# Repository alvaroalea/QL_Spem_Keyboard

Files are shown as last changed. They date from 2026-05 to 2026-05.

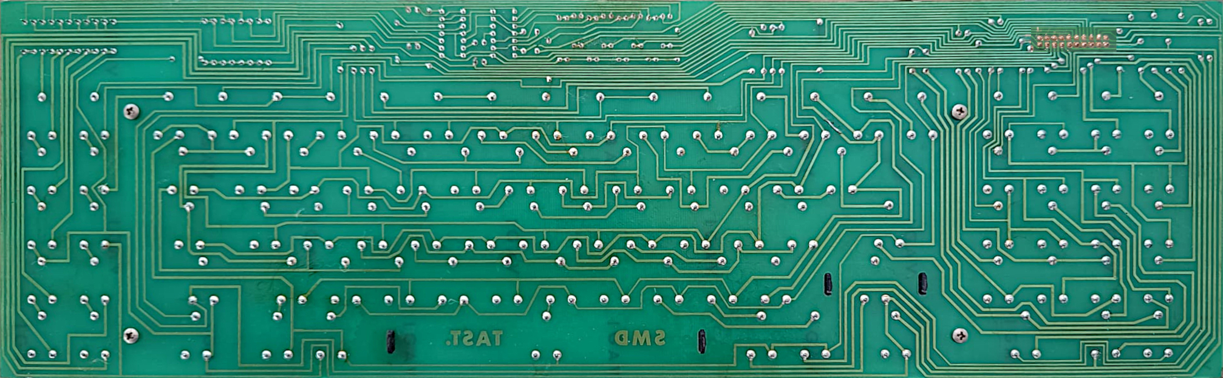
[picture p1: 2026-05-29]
Docs/PCB_solderside2.jpeg

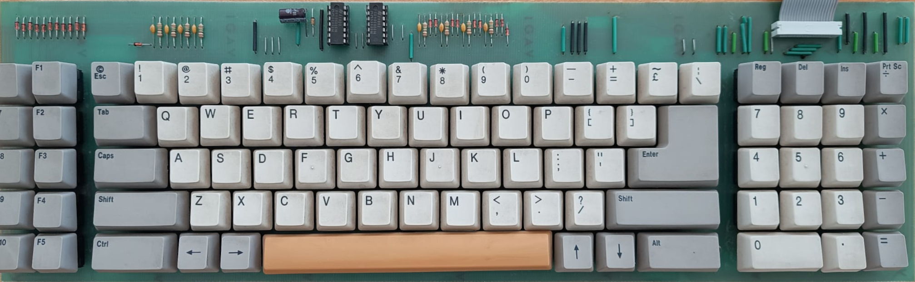
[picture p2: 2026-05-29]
Docs/PCB_compside2.jpeg

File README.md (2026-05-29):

# QL_Spem_Keyboard

Recreation of the mechanical keyboard for Sinclair QL computer by brand Spem

# WARNING: DO NOT USE THIS PROJECT IS NOT TESTED AND MISSING THINGS

Spem SRL, a italian company manufacture in 1986 a conversion kit for the Sinclair QL, named "System 2",
This include a aluminium desktop case with space for up to two 3 1/2" drives, the QL original Power supply and a Sinclair QL main board, to create a complete moderm desktop computer.

The case also incorporate a backplane where you can install a memory expansion and a disk interface.

The System 2 come with a full mechanical Keyboard, including numeric keys and 10 function keys, Spem use a unique aproach, and instead to provida a normal PC keyboard with a DIN-5 conector, design a specific one that connect directly to the keyboard conectors of the original Sinclair QL, and provide the aditional keys.

This is easy identificable because of the 20 cores ribbon cable the go from the keyboard to the case.

This project try to recreate this keyboard as identical as possible.
 
# Technical Details

The keyboard use keyswitch from Japanesse brand Futaba, referene MA-41 "Tombstone" because the top of the key is similar a tomb stone, with a cross emboss in the middle, while today's tipical keyswitchs the cross raise over the key.

This keyswitch has 3 legs, 2 of they are probably internally conected, to facilitate the develop of matrix keyboards using only 1 side of the PCB.

The combinations of keys need for some keys, like the F-5 F-10 that are really F1 to F5 at same time that shift keys, are from a pair of IC of type 4066, that are integrated analog swites, to power this 2 ic a small circuit drain the power from the keyboards lines itself.

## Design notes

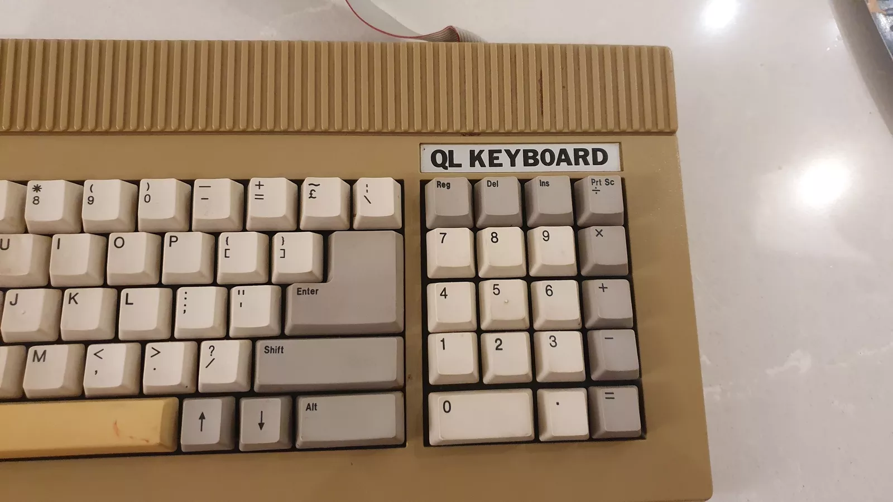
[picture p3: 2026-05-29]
Docs/s-l1601.webp

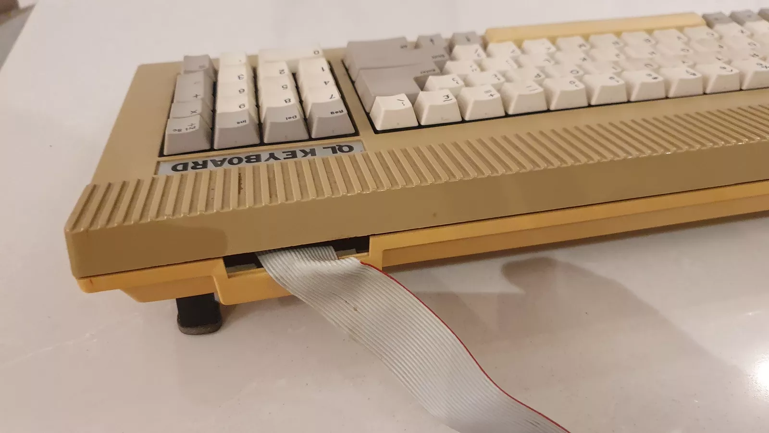
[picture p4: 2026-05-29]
Docs/s-l1611.webp

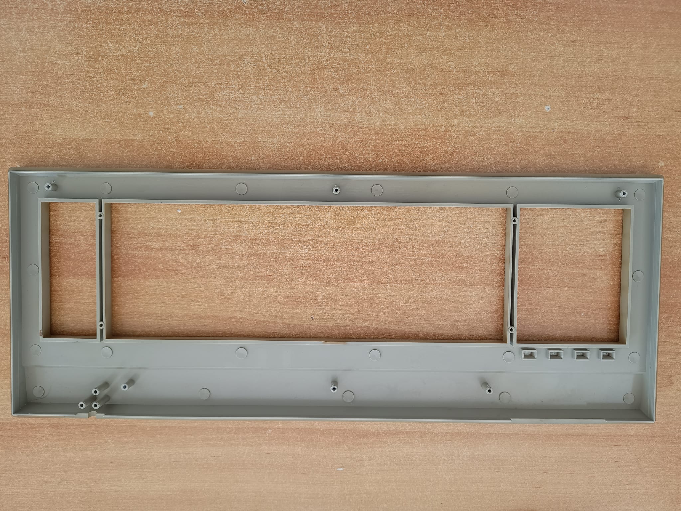
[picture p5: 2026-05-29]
Docs/Sin título4.jpeg

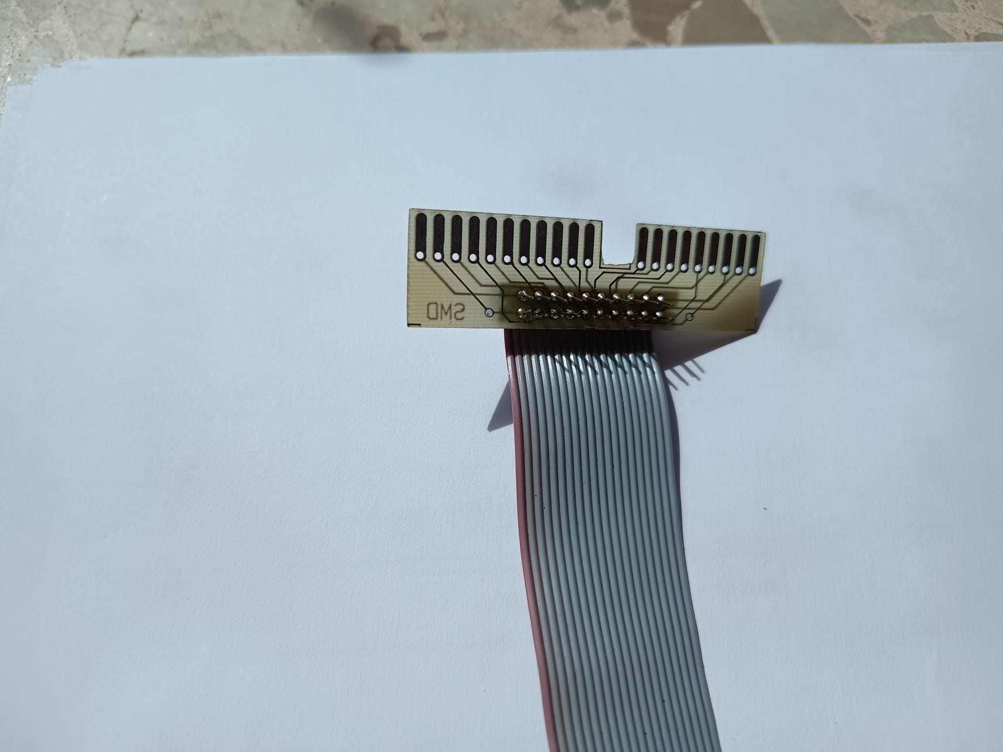
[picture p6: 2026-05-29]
Docs/Sin título9.jpeg

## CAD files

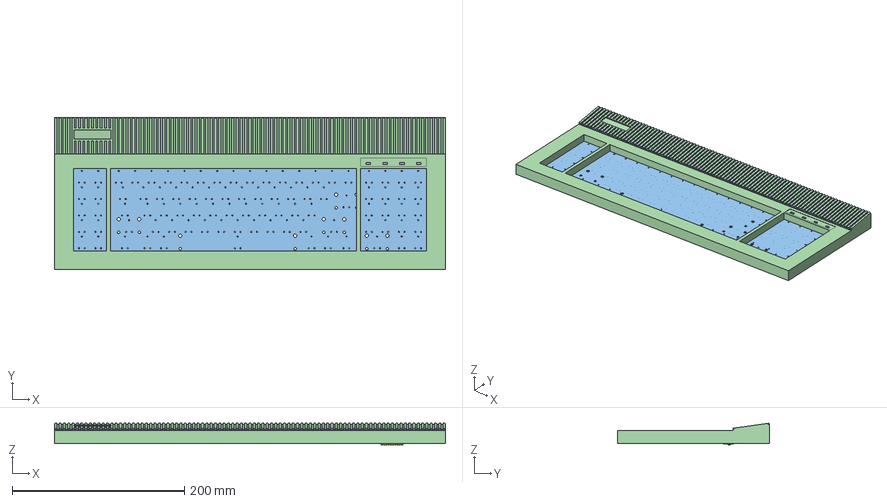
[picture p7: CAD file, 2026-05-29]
3D/SPEM_Case.FCStd
454.0 x 176.0 x 25.1 mm
D_DO-35_SOD27_P10.16mm_Horizontal
R_Axial_DIN0207_L6.3mm_D2.5mm_P10.16mm_Horizontal
R_Axial_DIN0207_L6.3mm_D2.5mm_P10.16mm_Horizontal001
R_Axial_DIN0207_L6.3mm_D2.5mm_P10.16mm_Horizontal002
R_Axial_DIN0207_L6.3mm_D2.5mm_P10.16mm_Horizontal003
R_Axial_DIN0207_L6.3mm_D2.5mm_P10.16mm_Horizontal004
D_DO-35_SOD27_P12.70mm_Horizontal
D_DO-35_SOD27_P10.16mm_Horizontal001
DIP-14_W7.62mm
D_DO-35_SOD27_P10.16mm_Horizontal002
R_Axial_DIN0207_L6.3mm_D2.5mm_P10.16mm_Horizontal005
D_DO-35_SOD27_P10.16mm_Horizontal003
D_DO-35_SOD27_P10.16mm_Horizontal004
D_DO-35_SOD27_P10.16mm_Horizontal005
D_DO-35_SOD27_P10.16mm_Horizontal006
C_Axial_L3.8mm_D2.6mm_P12.50mm_Horizontal
D_DO-35_SOD27_P10.16mm_Horizontal007
D_DO-35_SOD27_P7.62mm_Horizontal
D_DO-35_SOD27_P10.16mm_Horizontal008
D_DO-35_SOD27_P10.16mm_Horizontal009
D_DO-35_SOD27_P10.16mm_Horizontal010
D_DO-35_SOD27_P10.16mm_Horizontal011
R_Axial_DIN0207_L6.3mm_D2.5mm_P10.16mm_Horizontal006
D_DO-35_SOD27_P10.16mm_Horizontal012
R_Axial_DIN0207_L6.3mm_D2.5mm_P10.16mm_Horizontal007
R_Axial_DIN0207_L6.3mm_D2.5mm_P10.16mm_Horizontal008
R_Axial_DIN0207_L6.3mm_D2.5mm_P10.16mm_Horizontal009
R_Axial_DIN0207_L6.3mm_D2.5mm_P10.16mm_Horizontal010
R_Axial_DIN0207_L6.3mm_D2.5mm_P10.16mm_Horizontal011
D_DO-35_SOD27_P10.16mm_Horizontal013
D_DO-35_SOD27_P10.16mm_Horizontal014
DIP-14_W7.62mm001
R_Axial_DIN0207_L6.3mm_D2.5mm_P10.16mm_Horizontal012
R_Axial_DIN0207_L6.3mm_D2.5mm_P10.16mm_Horizontal013
D_DO-35_SOD27_P10.16mm_Horizontal015
D_DO-35_SOD27_P10.16mm_Horizontal016
R_Axial_DIN0207_L6.3mm_D2.5mm_P10.16mm_Horizontal014
D_DO-35_SOD27_P10.16mm_Horizontal017
D_DO-35_SOD27_P10.16mm_Horizontal018
D_DO-35_SOD27_P10.16mm_Horizontal019
R_Axial_DIN0207_L6.3mm_D2.5mm_P10.16mm_Horizontal015
PinHeader_2x10_P2.54mm_Horizontal
SPEN SINCLAIR QL_PCB
Cuerpo

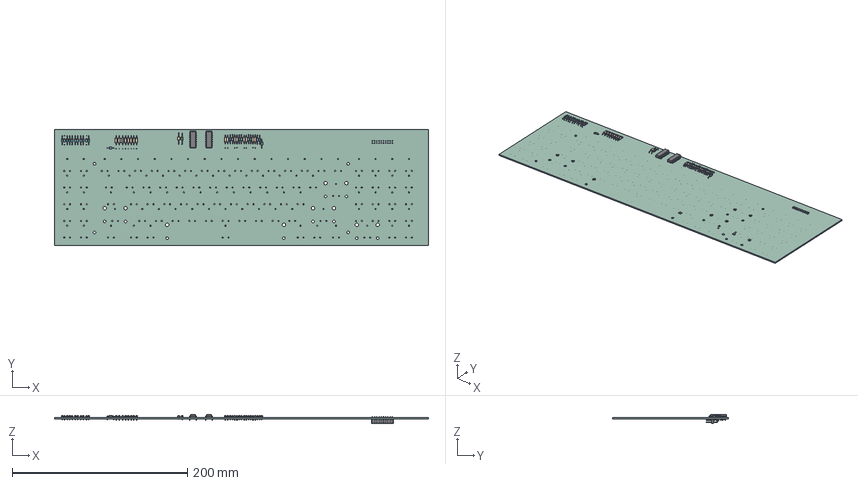
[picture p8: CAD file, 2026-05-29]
SPEN SINCLAIR QL/SPEN SINCLAIR QL.step
427.4 x 132.2 x 10.4 mm
D_DO-35_SOD27_P10.16mm_Horizontal x 20
R_Axial_DIN0207_L6.3mm_D2.5mm_P10.16mm_Horizontal x 16
D_DO-35_SOD27_P12.70mm_Horizontal
DIP-14_W7.62mm x 2
C_Axial_L3.8mm_D2.6mm_P12.50mm_Horizontal
D_DO-35_SOD27_P7.62mm_Horizontal
PinHeader_2x10_P2.54mm_Horizontal
SPEN SINCLAIR QL_PCB

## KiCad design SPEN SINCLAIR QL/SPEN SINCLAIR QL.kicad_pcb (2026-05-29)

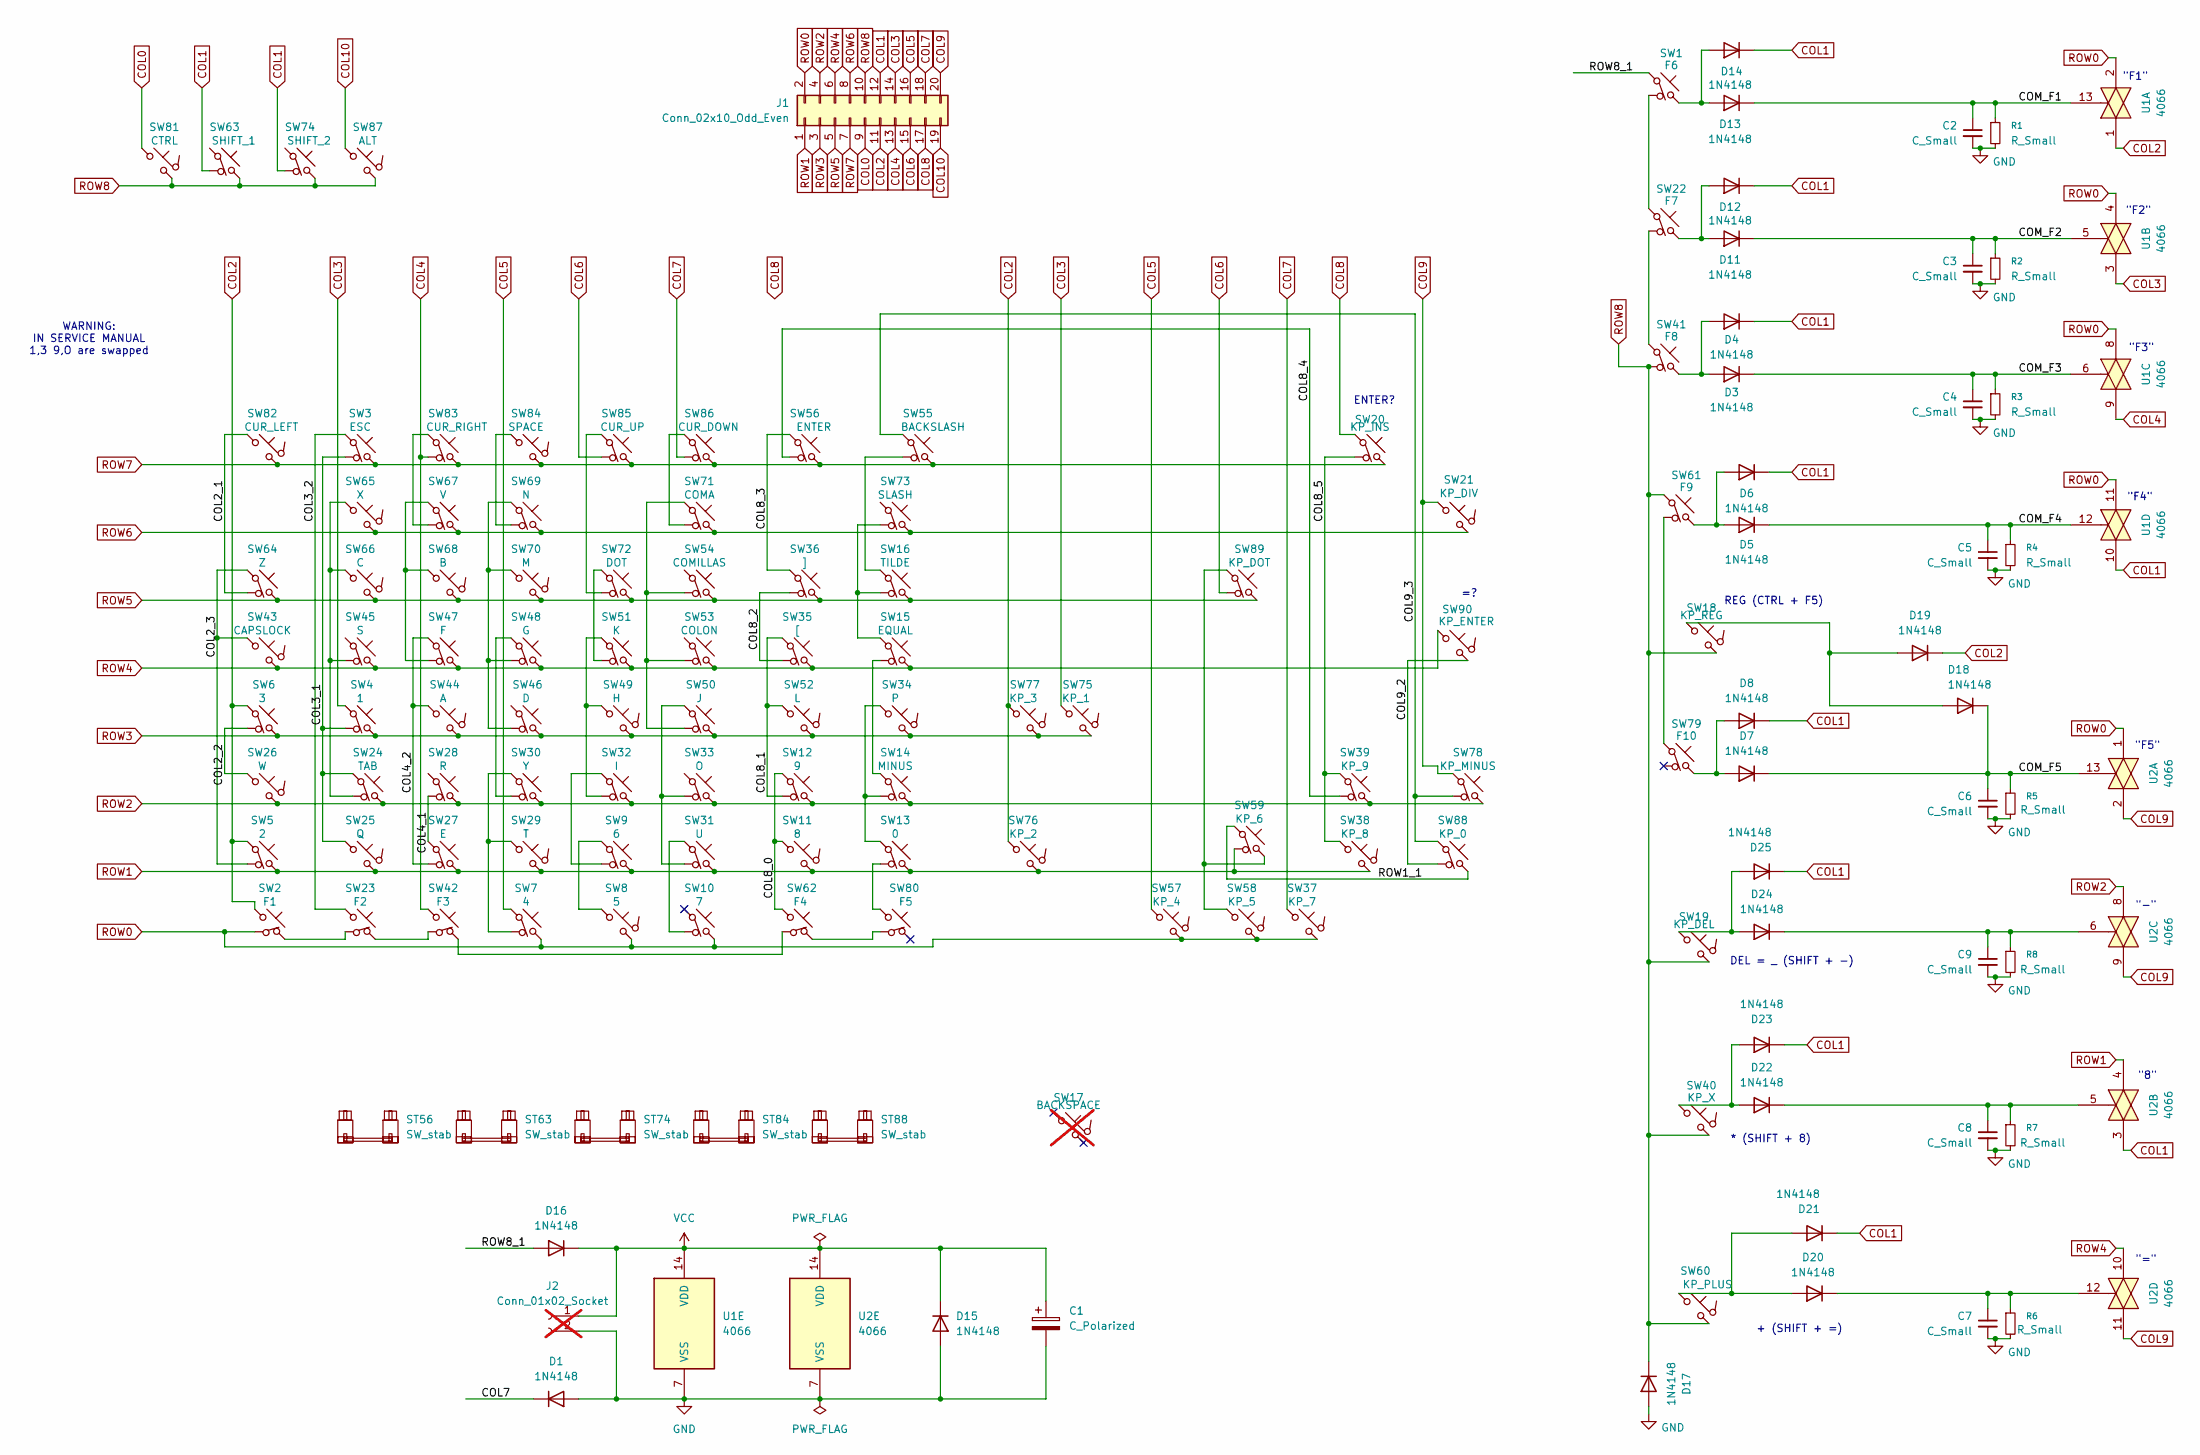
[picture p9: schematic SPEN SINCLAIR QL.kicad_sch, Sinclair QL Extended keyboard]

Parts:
C1: C_Polarized; C_Axial_L3.8mm_D2.6mm_P12.50mm_Horizontal
C2, C3, C4, C5, C6, C7, C8, C9: C_Small; C_Axial_DIN0207_L6.3mm_D2.5mm_P14.73mm_Horizontal
D1, D3, D4, D5, D6, D7, D8, D11, D12, D13, D14, D16, D18, D19, D20, D21, D22, D23, D24, D25: 1N4148; D_DO-35_SOD27_P10.16mm_Horizontal
D15: 1N4148; D_DO-35_SOD27_P12.70mm_Horizontal
D17: 1N4148; D_DO-35_SOD27_P7.62mm_Horizontal
J1: Conn_02x10_Odd_Even; PinHeader_2x10_P2.54mm_Horizontal
J2: Conn_01x02_Socket; PinHeader_1x02_P2.54mm_Horizontal; not fitted
R1, R2, R3, R4, R5, R6, R7, R8: R_Small; R_Axial_DIN0207_L6.3mm_D2.5mm_P14.73mm_Horizontal
ST56, ST63, ST74, ST88: SW_stab; Stabilizer_Cherry_MX_2.00u
ST84: SW_stab; Stabilizer_Cherry_MX_8.00u
SW1: F6; SW_Futaba_MA_PCB_1.00u
SW2: F1; SW_Futaba_MA_PCB_1.00u
SW3: ESC; SW_Futaba_MA_PCB_1.00u
SW4: 1; SW_Futaba_MA_PCB_1.00u
SW5: 2; SW_Futaba_MA_PCB_1.00u
SW6: 3; SW_Futaba_MA_PCB_1.00u
SW7: 4; SW_Futaba_MA_PCB_1.00u
SW8: 5; SW_Futaba_MA_PCB_1.00u
SW9: 6; SW_Futaba_MA_PCB_1.00u
SW10: 7; SW_Futaba_MA_PCB_1.00u
SW11: 8; SW_Futaba_MA_PCB_1.00u
SW12: 9; SW_Futaba_MA_PCB_1.00u
SW13: 0; SW_Futaba_MA_PCB_1.00u
SW14: MINUS; SW_Futaba_MA_PCB_1.00u
SW15: EQUAL; SW_Futaba_MA_PCB_1.00u
SW16: TILDE; SW_Futaba_MA_PCB_1.00u
SW17: BACKSPACE; SW_Futaba_MA_PCB_1.00u; not fitted
SW18: KP_REG; SW_Futaba_MA_PCB_1.00u
SW19: KP_DEL; SW_Futaba_MA_PCB_1.00u
SW20: KP_INS; SW_Futaba_MA_PCB_1.00u
SW21: KP_DIV; SW_Futaba_MA_PCB_1.00u
SW22: F7; SW_Futaba_MA_PCB_1.00u
SW23: F2; SW_Futaba_MA_PCB_1.00u
SW24: TAB; SW_Futaba_MA_PCB_1.00u
SW25: Q; SW_Futaba_MA_PCB_1.00u
SW26: W; SW_Futaba_MA_PCB_1.00u
SW27: E; SW_Futaba_MA_PCB_1.00u
SW28: R; SW_Futaba_MA_PCB_1.00u
SW29: T; SW_Futaba_MA_PCB_1.00u
SW30: Y; SW_Futaba_MA_PCB_1.00u
SW31: U; SW_Futaba_MA_PCB_1.00u
SW32: I; SW_Futaba_MA_PCB_1.00u
SW33: O; SW_Futaba_MA_PCB_1.00u
SW34: P; SW_Futaba_MA_PCB_1.00u
SW35: [; SW_Futaba_MA_PCB_1.00u
SW36: ]; SW_Futaba_MA_PCB_1.00u
SW37: KP_7; SW_Futaba_MA_PCB_1.00u
SW38: KP_8; SW_Futaba_MA_PCB_1.00u
SW39: KP_9; SW_Futaba_MA_PCB_1.00u
SW40: KP_X; SW_Futaba_MA_PCB_1.00u
SW41: F8; SW_Futaba_MA_PCB_1.00u
SW42: F3; SW_Futaba_MA_PCB_1.00u
SW43: CAPSLOCK; SW_Futaba_MA_PCB_1.00u
SW44: A; SW_Futaba_MA_PCB_1.00u
SW45: S; SW_Futaba_MA_PCB_1.00u
SW46: D; SW_Futaba_MA_PCB_1.00u
SW47: F; SW_Futaba_MA_PCB_1.00u
SW48: G; SW_Futaba_MA_PCB_1.00u
SW49: H; SW_Futaba_MA_PCB_1.00u
SW50: J; SW_Futaba_MA_PCB_1.00u
SW51: K; SW_Futaba_MA_PCB_1.00u
SW52: L; SW_Futaba_MA_PCB_1.00u
SW53: COLON; SW_Futaba_MA_PCB_1.00u
SW54: COMILLAS; SW_Futaba_MA_PCB_1.00u
SW55: BACKSLASH; SW_Futaba_MA_PCB_1.00u
SW56: ENTER; SW_Futaba_MA_PCB_1.00u
SW57: KP_4; SW_Futaba_MA_PCB_1.00u
SW58: KP_5; SW_Futaba_MA_PCB_1.00u
SW59: KP_6; SW_Futaba_MA_PCB_1.00u
SW60: KP_PLUS; SW_Futaba_MA_PCB_1.00u
SW61: F9; SW_Futaba_MA_PCB_1.00u
SW62: F4; SW_Futaba_MA_PCB_1.00u
SW63: SHIFT_1; SW_Futaba_MA_PCB_1.00u
SW64: Z; SW_Futaba_MA_PCB_1.00u
SW65: X; SW_Futaba_MA_PCB_1.00u
SW66: C; SW_Futaba_MA_PCB_1.00u
SW67: V; SW_Futaba_MA_PCB_1.00u
SW68: B; SW_Futaba_MA_PCB_1.00u
SW69: N; SW_Futaba_MA_PCB_1.00u
SW70: M; SW_Futaba_MA_PCB_1.00u
SW71: COMA; SW_Futaba_MA_PCB_1.00u
SW72: DOT; SW_Futaba_MA_PCB_1.00u
SW73: SLASH; SW_Futaba_MA_PCB_1.00u
SW74: SHIFT_2; SW_Futaba_MA_PCB_1.00u
SW75: KP_1; SW_Futaba_MA_PCB_1.00u
SW76: KP_2; SW_Futaba_MA_PCB_1.00u
SW77: KP_3; SW_Futaba_MA_PCB_1.00u
SW78: KP_MINUS; SW_Futaba_MA_PCB_1.00u
SW79: F10; SW_Futaba_MA_PCB_1.00u
SW80: F5; SW_Futaba_MA_PCB_1.00u
SW81: CTRL; SW_Futaba_MA_PCB_1.00u
SW82: CUR_LEFT; SW_Futaba_MA_PCB_1.00u
SW83: CUR_RIGHT; SW_Futaba_MA_PCB_1.00u
SW84: SPACE; SW_Futaba_MA_PCB_1.00u
SW85: CUR_UP; SW_Futaba_MA_PCB_1.00u
SW86: CUR_DOWN; SW_Futaba_MA_PCB_1.00u
SW87: ALT; SW_Futaba_MA_PCB_1.00u
SW88: KP_0; SW_Futaba_MA_PCB_1.00u
SW89: KP_DOT; SW_Futaba_MA_PCB_1.00u
SW90: KP_ENTER; SW_Futaba_MA_PCB_1.00u
U1, U2: 4066; DIP-14_W7.62mm_LongPads

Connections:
/COL2_1: SW64.3, SW82.1
/COL2_2: SW6.3, SW26.1
/COL2_3: SW5.3, SW43.1, SW64.1
/COL3_1: SW3.3, SW4.3, SW24.1, SW25.1
/COL3_2: SW3.1, SW23.2
/COL4_1: SW27.1, SW28.3
/COL4_2: SW27.3, SW44.1, SW47.1
/COL8_0: SW11.1, SW12.1, SW62.2
/COL8_1: SW12.3, SW35.1, SW52.1
/COL8_2: SW35.3, SW36.3
/COL8_3: SW36.1, SW56.1
/COL8_4: SW39.3, SW56.3
/COL8_5: SW20.3, SW38.1, SW39.1
/COL9_2: SW88.3, SW90.2
/COL9_3: SW55.1, SW78.3, SW88.1
/COM_F1: C2.1, D13.1 (K), R1.1, U1.13
/COM_F2: C3.1, D11.1 (K), R2.1, U1.5
/COM_F3: C4.1, D3.1 (K), R3.1, U1.6
/COM_F4: C5.1, D5.1 (K), R4.1, U1.12
/COM_F5: C6.1, D7.1 (K), D18.1 (K), R5.1, U2.13
/ROW1_1: SW59.1, SW88.2
/ROW8_1: D16.2 (A), SW1.1
COL0: J1.9, SW81.1
COL1: D4.1 (K), D6.1 (K), D8.1 (K), D12.1 (K), D14.1 (K), D21.1 (K), D23.1 (K), D25.1 (K), J1.12, SW63.3, SW74.3, U1.10, U2.3
COL2: D19.1 (K), J1.11, SW2.2, SW5.1, SW6.1, SW76.1, SW77.1, U1.1
COL3: J1.14, SW4.1, SW75.1, U1.3
COL4: J1.13, SW42.2, SW83.3, U1.9
COL5: J1.16, SW7.1, SW57.1
COL6: J1.15, SW85.3, SW89.3
COL7: D1.1 (K), J1.18, SW37.1, SW86.3
COL8: J1.17, SW20.1
COL9: J1.20, SW21.1, SW78.1, U2.2, U2.9, U2.11
COL10: J1.19, SW87.1
COM_8: C8.1, D22.1 (K), R7.1, U2.5
COM_MINUS: C9.1, D24.1 (K), R8.1, U2.6
COM_PLUS: C7.1, D20.1 (K), R6.1, U2.12
GND: C1.2, C2.2, C3.2, C4.2, C5.2, C6.2, C7.2, C8.2, C9.2, D1.2 (A), D15.2 (A), D17.2 (A), J2.2, R1.2, R2.2, R3.2, R4.2, R5.2, R6.2, R7.2, R8.2, U1.7 (VSS), U2.7 (VSS)
unnamed: D3.2 (A), D4.2 (A), SW41.2
unnamed: D5.2 (A), D6.2 (A), SW61.2
unnamed: D7.2 (A), D8.2 (A), SW79.2
unnamed: D11.2 (A), D12.2 (A), SW22.2
unnamed: D13.2 (A), D14.2 (A), SW1.2
unnamed: D18.2 (A), D19.2 (A), SW18.1
unnamed: D20.2 (A), D21.2 (A), SW60.1
unnamed: D22.2 (A), D23.2 (A), SW40.1
unnamed: D24.2 (A), D25.2 (A), SW19.1
unnamed: SW1.3, SW22.1
unnamed: SW2.3, SW23.1
unnamed: SW8.1, SW9.1
unnamed: SW10.3, SW31.1
unnamed: SW13.1, SW80.2
unnamed: SW13.3, SW14.3, SW34.1
unnamed: SW14.1, SW15.3
unnamed: SW15.1, SW16.3, SW73.3
unnamed: SW16.1, SW55.3
unnamed: SW22.3, SW41.1
unnamed: SW23.3, SW42.1
unnamed: SW24.3, SW45.3, SW65.1, SW66.1
unnamed: SW7.3, SW29.1, SW30.1
unnamed: SW30.3, SW48.1
unnamed: SW31.3, SW33.3, SW50.1
unnamed: SW9.3, SW32.1
unnamed: SW32.3, SW49.1, SW51.1
unnamed: SW42.3, SW62.1
unnamed: SW46.3, SW48.3, SW69.1, SW70.1
unnamed: SW47.3, SW67.1, SW68.1
unnamed: SW50.3, SW53.3, SW54.3, SW71.1
unnamed: SW51.3, SW72.1
unnamed: SW58.1, SW59.2, SW89.1
unnamed: SW61.3, SW79.1
unnamed: SW62.3, SW80.1
unnamed: SW67.3, SW83.1
unnamed: SW69.3, SW84.1
unnamed: SW71.3, SW86.1
unnamed: SW72.3, SW85.1
ROW0: J1.2, SW2.1, SW7.2, SW8.2, SW10.2, SW37.2, SW57.2, SW58.2, U1.2, U1.4, U1.8, U1.11, U2.1
ROW1: J1.1, SW5.2, SW9.2, SW11.2, SW13.2, SW25.2, SW27.2, SW29.2, SW31.2, SW38.2, SW59.3, SW76.2, U2.4
ROW2: J1.4, SW12.2, SW14.2, SW24.2, SW26.2, SW28.2, SW30.2, SW32.2, SW33.2, SW39.2, SW78.2, U2.8
ROW3: J1.3, SW4.2, SW6.2, SW34.2, SW44.2, SW46.2, SW49.2, SW50.2, SW52.2, SW75.2, SW77.2
ROW4: J1.6, SW15.2, SW35.2, SW43.2, SW45.2, SW47.2, SW48.2, SW51.2, SW53.2, SW90.1, U2.10
ROW5: J1.5, SW16.2, SW36.2, SW54.2, SW64.2, SW66.2, SW68.2, SW70.2, SW72.2, SW89.2
ROW6: J1.8, SW21.2, SW65.2, SW67.2, SW69.2, SW71.2, SW73.2
ROW7: J1.7, SW3.2, SW20.2, SW55.2, SW56.2, SW82.2, SW83.2, SW84.2, SW85.2, SW86.2
ROW8: D17.1 (K), J1.10, SW18.2, SW19.2, SW40.2, SW41.3, SW60.2, SW61.1, SW63.2, SW74.2, SW81.2, SW87.2
VCC: C1.1, D15.1 (K), D16.1 (K), J2.1, U1.14 (VDD), U2.14 (VDD)

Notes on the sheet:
DEL = _ (SHIFT + -)
ENTER?
"F2"
"8"
"-"
"F3"
REG (CTRL + F5)
"="
WARNING: IN SERVICE MANUAL 1,3 9,O are swapped
"F5"
* (SHIFT + 8)
"F4"
+ (SHIFT + =)
"F1"

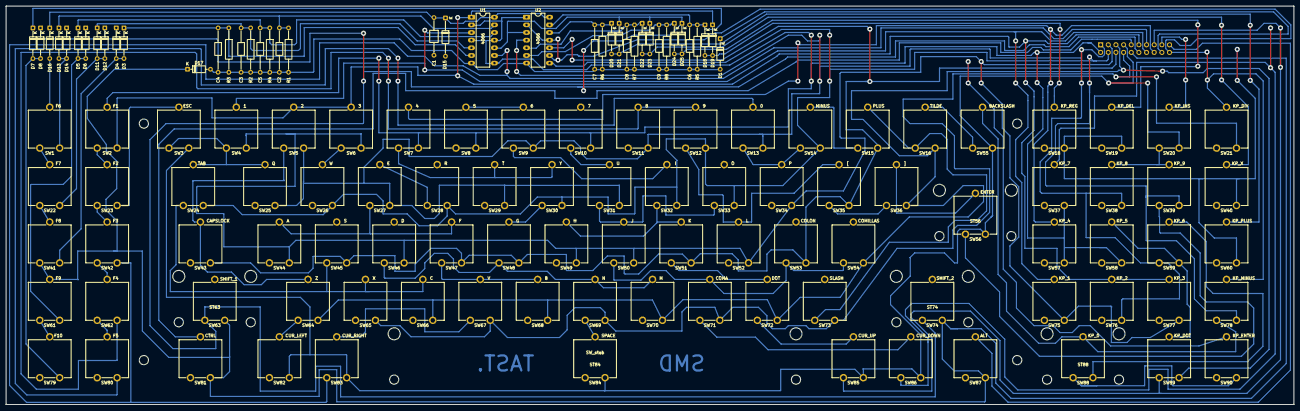
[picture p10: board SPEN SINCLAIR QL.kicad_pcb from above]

Board: 2 copper layers, 427.4 x 132.2 mm, 136 parts (1 on the bottom side), 85 nets.
